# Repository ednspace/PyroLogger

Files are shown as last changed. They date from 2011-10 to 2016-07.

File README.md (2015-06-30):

For when you the Pyro, needs to log!!!
======================================

Summary
----

A long standing project (since early 2005) to log and provide real time graphing of wood, electric, or gas kiln firings.
This project by necessity requires a hardware and software combination and through the years many have been tried with 
varying degrees of success. Most attempts are preserved here for posterity sake.

The Current Version
-----------
The most recent version of the hardware uses the Teensy 3.1 for the microcontroller, a custom made daughter board that has an SD card and phone jack
 to connect the sensors. The sensors are [MAX31850K from Adafruit](http://www.adafruit.com/products/1727). The GUI is now handled with a customized interface
 for the amazing [MegunoLink](http://www.megunolink.com/).
 While buying modular hardware and using software that requires a modest licensing fee adds to the overall build cost it makes the 
 hardware and software a bit more accessible to the novice experimenter. 
 Hopefully this will enable more people to get at their kiln data and improve their future firings and learn from the ones they have done in the past.

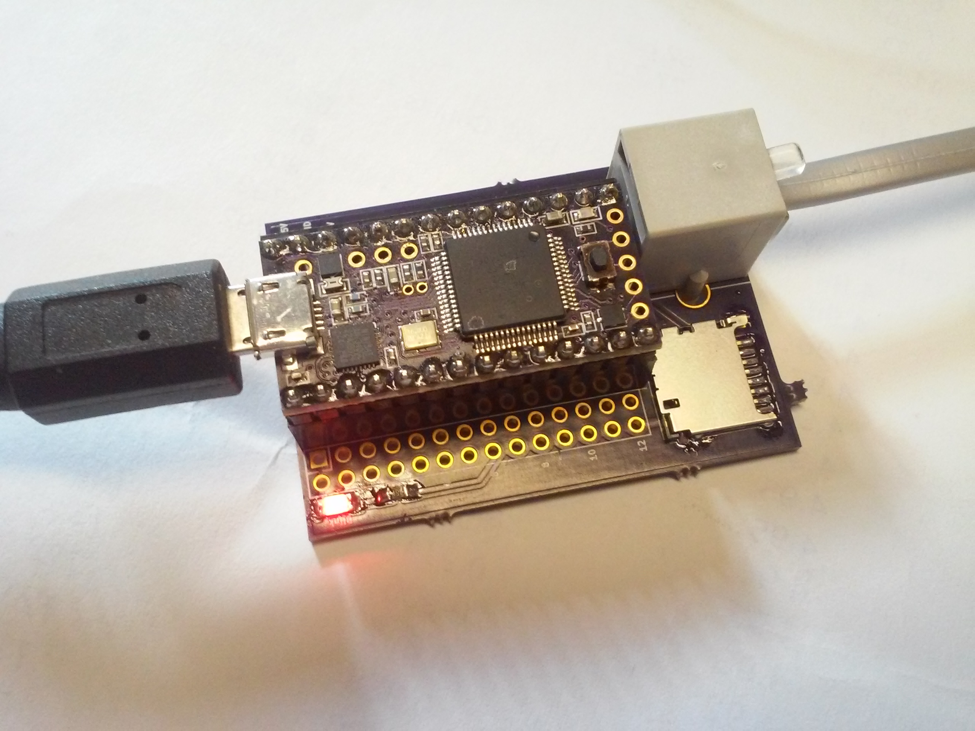
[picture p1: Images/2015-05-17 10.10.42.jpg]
Image of populated board

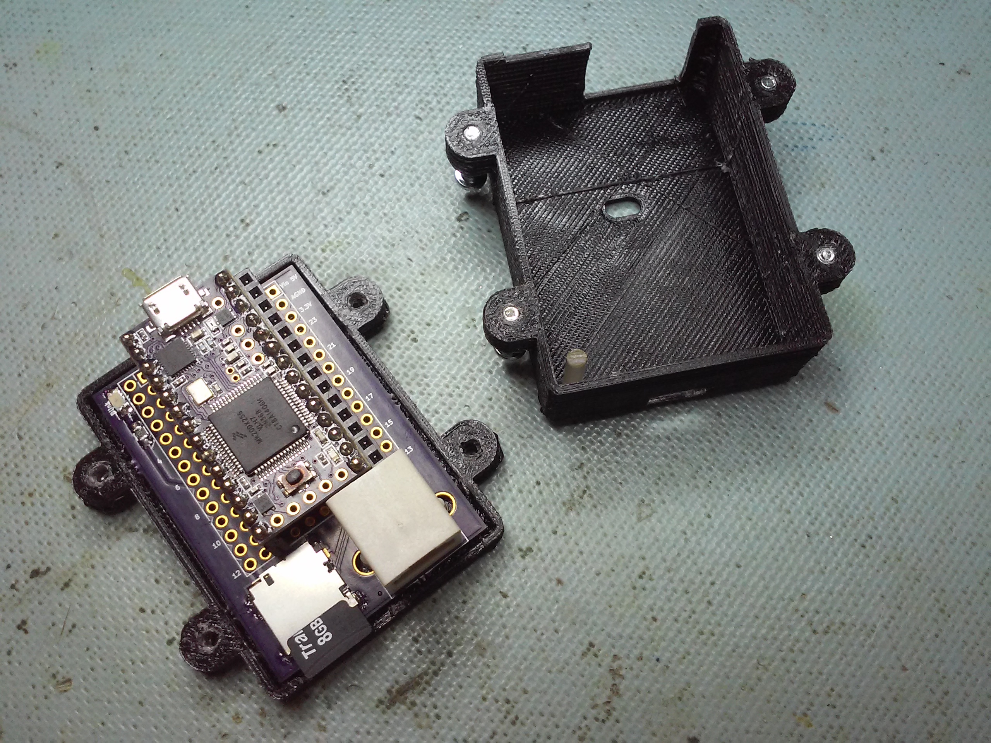
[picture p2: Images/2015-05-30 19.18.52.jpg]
Image of 3D enclosure split open

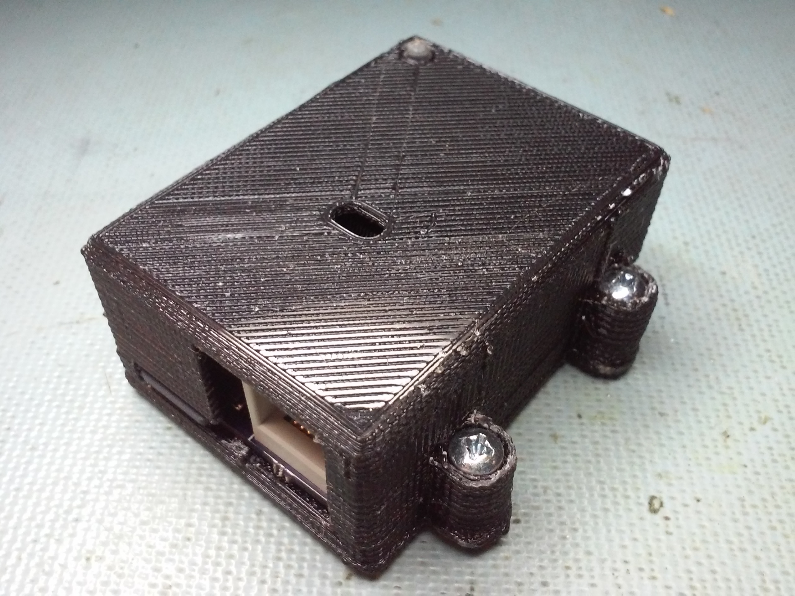
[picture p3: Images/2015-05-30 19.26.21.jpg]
Image of 3D enclosure closed up

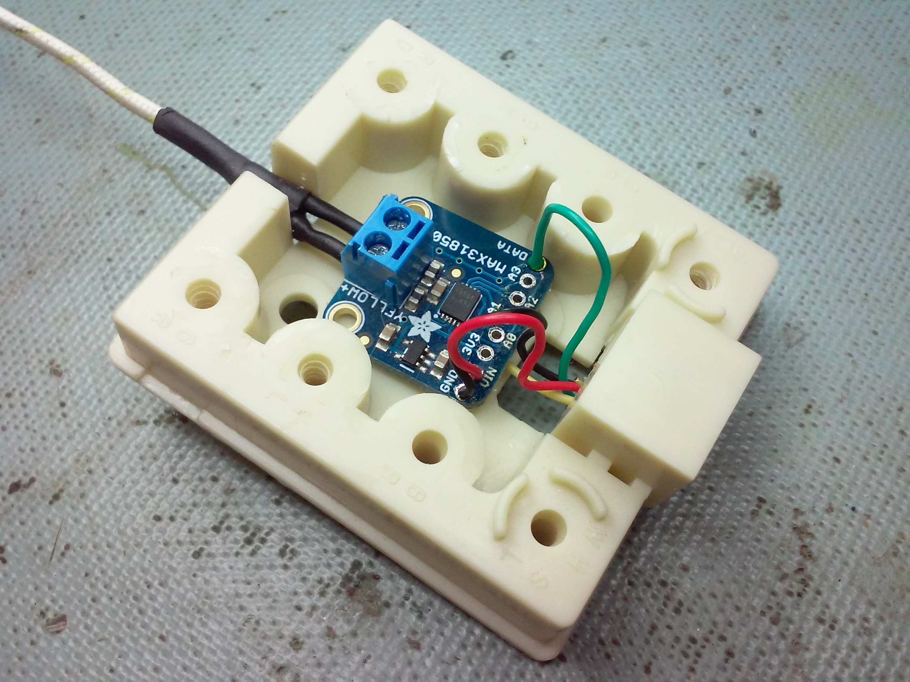
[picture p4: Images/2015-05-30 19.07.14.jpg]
Image of the sensor board in the phone box

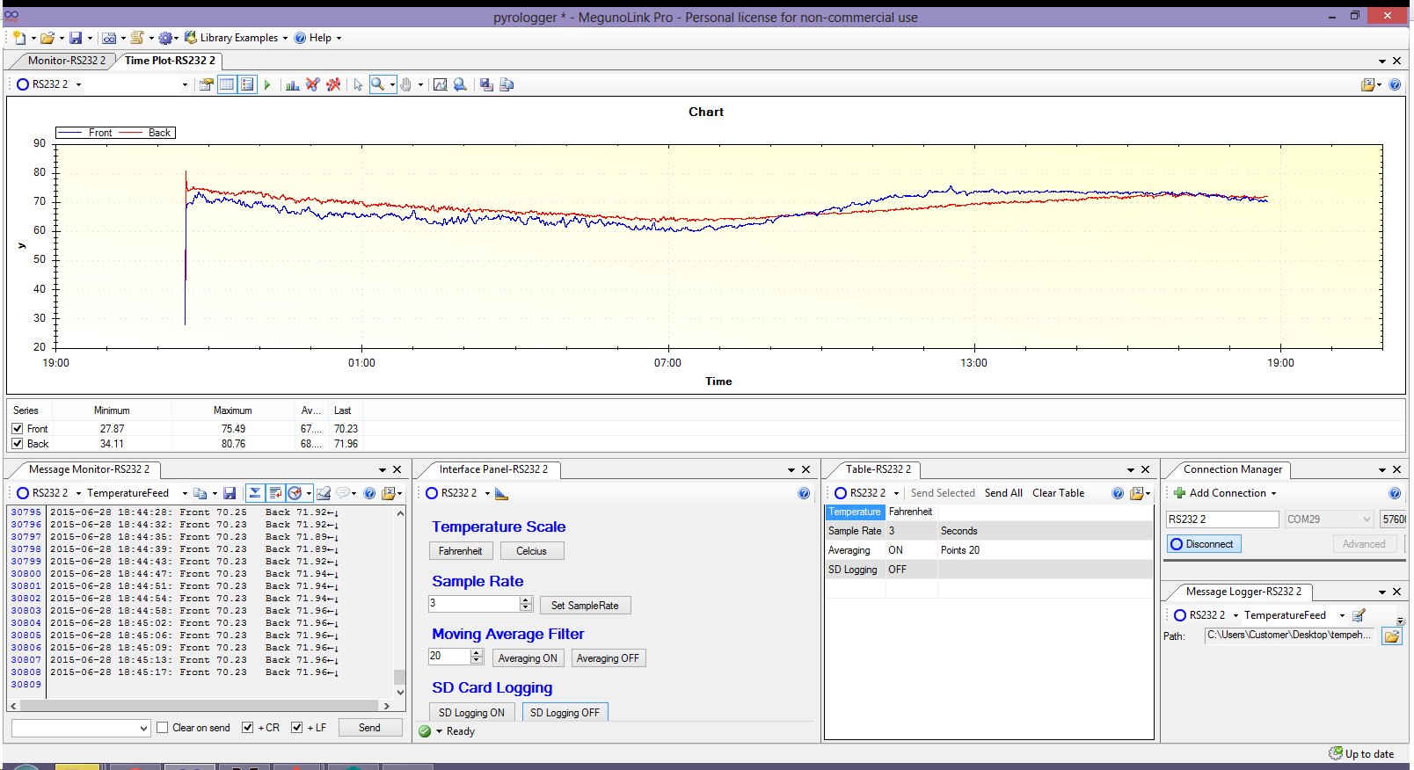
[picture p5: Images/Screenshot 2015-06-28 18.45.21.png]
Image of the GUI

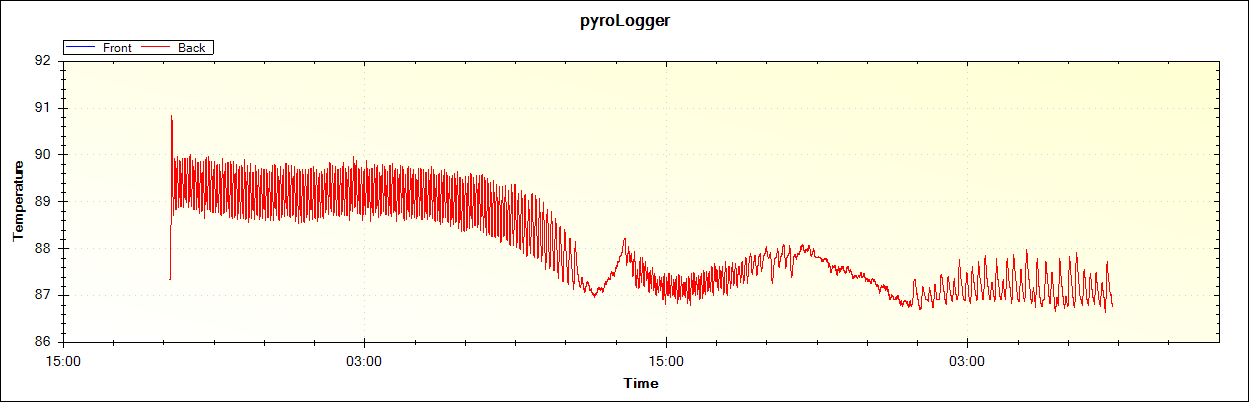
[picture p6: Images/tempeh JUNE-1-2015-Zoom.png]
Image of zoomed in Tempeh graph


History
-----
If you dig around in the archives you will find early versions of the code that relied on Python, WxPython for a GUI, and provided a front end for a custom piece of hardware. The hardware at that time was based on a microchip PIC microcontroller and addressed a one wire bus and a DS2760A to ultimately digitize two analog type K thermocouples. The combination of hardware and software was used to collect, display and log the temperature. Many variations of the code are here and all of hardware versions of the electronics also. Many early graphs generated with that hardware software combination are in the testing folder. Most of the work was done on the WxGauge and GUI versions. Its not very organized, but feel free to poke around and use what you need.

Enjoy... ED

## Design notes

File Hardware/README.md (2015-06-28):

Hardware Lives Here
---------

The folder Pyrologger_V3_KiCad contains the latest board files. Its a daughter board for 
the teensy 3.1 that has connections for the thermocouple sensors and an SD card.

The folder ds2760-pcb contains the orginal board files for the pyrometer 
sensor. The chip is a ds2760 lithium ion battery monitor from Maxim now 
Dallas Semiconductor.  It uses the one wire bus to get the mv drop over 
the shunt resistor which in this case is actually a type K 
thermocouple. The files where generated with Linux-PCB and the 
schematics are in gschem.  The LMD file is for driving an LPKF circuit 
board plotter to cut out the board.

The folder 16F88_FT232RL contains the board files and schematic for the 
microcontroller interface to the computer.  It uses a microchip 
technology 16F88 and an FTDI chip to make a serial connection through 
USB.  The microcontroller board is accessed with by the wxPython GUI 
software which collects the data and displays it on screen.  The board 
files where done with Eagle.

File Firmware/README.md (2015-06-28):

Latest Micro Code Lives Here
----
Current Version is in pyroLogger_V3_Teensy3.1
Enjoy... ED

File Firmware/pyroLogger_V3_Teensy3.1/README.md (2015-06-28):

Current Codebase
________________
This folder contains the newest code for the pyrologger project.
It uses Megunolink Pro as a GUI interface and computer display panel
to connect to the hardware and graph data coming from two thermocouple sensor 
modules.

The file pyrologger.mlx can be opened by Megunolink to display the GUI.

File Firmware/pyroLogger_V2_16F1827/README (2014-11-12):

PyrologgerV2

This is an updated version of the old Pyrologger codebase. It will feature a PyQT/QWT GUI interface to a custom hardware control board. The new board will have an upgraded microcontroller, the PIC 16F1827 and a Dallas 1 Wire Bus Master chip and an FTDI serial to USB converter for interaction with the computer.

It is planned to bring out all of the old Pyrologger features but finally move to a more robust hardware platform. There will eventually be software enhancements as well, once all the bugs are worked out with the new hardware. 

I will be keeping Firmware code, GUI code, and board files for the interface board as well as the thermocouple sensors all under this new GIT repository.

As they say, stay tuned!

LICENSE:

The Hardware and software in this project are released under the Creative Commons Attribution-Share Alike 3.0 United States License.

http://creativecommons.org/licenses/by-sa/3.0/deed.en_US

You may reproduce it for both your own personal use, and for commercial use if you provide a link to the original creator of the project on any documentation or website.

You may also modify the files, but you must then release them as well under the same terms.

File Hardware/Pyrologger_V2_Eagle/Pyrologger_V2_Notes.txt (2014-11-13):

Pyrologger

It seems I used the DS2760 for the sensor in the orginal design the new chip is now DS2762, its an upgrade from DS2760,DS2761 to the new DS2762. Its about 7.25 from mouser for a single chip...

DS2764 is a 2-wire version I2C otherwise looks the same, I think you can get a unique address...

Since I just saw a chip that claims to be latest greatest for thermocouples MAX3185 again I went to investigate. Most of these chips can go to extreme end for type K that a Kiln requires. From the data sheet.

VOUT = (41.276FV/NC) x (TR - TAMB)
where VOUT is the thermocouple output voltage (FV), TR
is the temperature of the remote thermocouple junction
(NC), and TAMB is the temperature of the device (NC).
Other thermocouple types use a similar straight-line
approximation but with different gain terms. Note that the
MAX31855 assumes a linear relationship between temperature
and voltage. Because all thermocouples exhibit
some level of nonlinearity, apply appropriate correction
to the device’s output data.

That last sentance scares me a little linear equation for a nonlinear device, I guess thats one way to do it...
Oh and at this time its $8.

Looks like if I use one wire and really want to use distances longer then a meter I may need to finally upgade to a bus maser chip, talk serial to it and let it handle the one wire bus. Course I have been living without this for a long long time now but...

DS2480 is the chip

And this is a good starter article http://www.maximintegrated.com/app-notes/index.mvp/id/4206

Looks like the DS2482 is the animal I need only a 1.66 little 8 pin bus master. Should be able to handle the bus and the micro can speak to it via I2C. Non Brainer

I have 2 sample chips of DS2762

and RJ11 socket with a footprint
https://www.sparkfun.com/products/132

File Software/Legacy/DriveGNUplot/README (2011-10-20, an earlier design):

Just a couple of perl scripts to plot data in gnuplot.
This was long before the wxPython GUI.
Here for archival purposes only...

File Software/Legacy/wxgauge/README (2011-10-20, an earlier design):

This is where the current version of the code lives...
wxthermo.py Reads and logs to the screen one thermocouple
wxthermo2.py Reads and logs two thermocouples
thermofunctions.py is an include file for repetitive tasks
images holds some of the icons for the GUI
graphs is a test folder containing saved graphs

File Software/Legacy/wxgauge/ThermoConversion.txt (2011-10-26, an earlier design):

Question:
How do you convert K-type thermocouple voltage to temperature using NIST polynomials?

Answer:
The NIST polynomials will produce a temperature conversion accuracy typically less than 0.06 degrees C error for K-type thermocouple.

NIST (National Institute of Standards and Technology) has published tables and equations that describe the voltage/temperature relationship. See PB93-190338, Temperature-Electromotive Force Reference Functions and Tables for the Letter-Designated Thermocouple Types Based on the ITS-90. NIST provides two forms of polynomials. The first provides voltage as a function of temperature, and the second provides temperature as a function of voltage. Both of these forms will be used in the procedure described here for doing a thermocouple temperature conversion.

The NIST tables and equations are all based on one end of the thermocouple (reference junction end) being at a temperature of 0 degrees Celsius. It is possible to avoid having a 0 degree reference junction. If the temperature of the reference junction is accurately known, then by using both the forward and inverse NIST polynomials the temperature of the thermocouple can be computed.

On a thermocouple, voltage is produced across the thermocouple leads that is proportional to the difference in temperature from one end of the thermocouple wire to the other. It is important to understand that voltage does not develop at the thermocouple junction but instead the voltage develops in the wire were ever a temperature gradient exists in the wire pair. Thermocouple:

      ------------------------------------------------------------\
     |    |--------->--------|    |------------->--------------|   \
     V  Vref                 |  Vmeas                          |    O    
     |    |----------<-------|    |-------------<--------------|   /
     -------------------------------------------------------------/
    ^                          ^                                    ^
    |                          |                                    |
  0 deg C                    Tref                                   T

The above diagram shows that: V If we know Tref, then Vref is calculated using the temperature to voltage form of the NIST equations. Vmeas is the voltage measured on the thermocouple. Adding Vmeas to the calculated Vref yields the voltage V that is then applied to the NIST voltage-to-temperature thermocouple equation to produce the final thermocouple temperature.

Tref is usually at about room temperature. A thermistor is usually used to sense this temperature.

Here is the complete algorithm which assumes that a 5K ohm thermistor is used to sense the reference junction temperature.

1. Measure the resistance of the thermistor on the reference junction. Compute the temperature of the reference junction (Tref) from the resistance reading. The following equation has less than 0.022 Deg C error for resistance between 92.7 (150 deg C) and 3.685e6 (-80 Deg C).

 Tref = temp. in degrees C
 
 Thr_ohms = resistance of 5K thermistor
 
 A = 1.28463e-3
 
 B = 0.23625e-3
 
 C = 9.2697e-8 
 
 W = ln(Thr_ohms)
 
 Tref = 1 / (A + W * (B+C * W*W)) - 273.15

The function ln is the logarithm (base e) or natural logarithm. Note that in HP BASIC, this is the keyword LOG.

2. Measure the voltage on the thermocouple connected to a channel (Vmeas).

3. Convert the thermistor temperature (Tref) to the equivalent thermocouple voltage (Vref). Use the temperature to voltage characteristics of the thermocouple measured in step 2.

K-type thermocouple temperature to voltage conversion:

 Vref = c0 + c1*Tref + c2*Tref^2 + c3*Tref^3 + c4*Tref^4 + c5*Tref^5 + 

 c6*Tref^6 + c7*Tref^7 + c8*Tref^8 + c9*Tref^9

The coefficients for temperature range 0 to 1372 deg C are:

 c0 = -1.7600413686 * 10^-2

 c1 = 3.8921204975 * 10^-2

 c2 = 1.8558770032 * 10^-5

 c3 = -9.9457592874 * 10^-8

 c4 = 3.1840945719 * 10^-10

 c5 = -5.6072844889 * 10^-13

 c6 = 5.6075059059 * 10^-16

 c7 = -3.2020720003 * 10^-19

 c8 = 9.7151147152 * 10^-23

 c9 = -1.2104721275 * 10^-26

4. Compute the compensated voltage (V) with the following formula: V=Vmeas + Vref

5. Convert the compensated voltage (V) calculated in step 4 to temperature (T). The equation for converting voltage (millivolts) to K-type thermocouple temperature in degrees Celsius is:

 T = c0 + c1*V + c2*V^2 + c3*V^3 + c4*V^4 + c5*V^5 + c6*V^6 + c7*V^7 +

 c8*V^8 + c9*V^9

 The coefficients for Temperature range -200 deg C to 0 deg C 

 Voltage range -5.891 mV to 0 mV

 Error Range .04 deg C to -.02 deg C are:

 C0 = 0

 C1 = 2.5173462 * 10^1

 C2 = -1.1662878

 C3 = -1.0833638

 C4 = -8.9773540 * 10^-1

 C5 = -3.7342377 * 10^-1

 C6 = -8.6632643 * 10^-2

 C7 = -1.0450598 * 10^-2

 C8 = -5.1920577 * 10^-4

 C9 = 0

 The coefficients for Temperature range 0 deg C to 500 deg C

 Voltage range 0 mV to 20.644 mV

 Error range .04 deg C to -.05 deg C are:

 C0 = 0

 C1 = 2.508355 * 10^1

 C2 = 7.860106 * 10^-2

 C3 = -2.503131 * 10^-1

 C4 = 8.315270 * 10^-2

 C5 = -1.228034 * 10^-2

 C6 = 9.804036 * 10^-4

 C7 = -4.413030 * 10^-5

 C8 = 1.057734 * 10^-6

 C9 = -1.052755 * 10^-8 

 The coefficients for Temperature range 500 deg C to 1372 deg C

 Voltage range 20.644 mV to 54.886 mV

 Error range .06 deg C to -.05 deg C are:

 C0 = -1.318058 * 10^2

 C1 = 4.830222 * 10^1

 C2 = -1.646031 

 C3 = 5.464731 * 10^-2

 C4 = -9.650715 * 10^-4

 C5 = 8.802193 * 10^-6

 C6 = -3.110810 * 10^-8

 C7 = 0

 C8 = 0

 C9 = 0

Remember to carry the correct units when using the tables or when using the polynomials in steps 3 and 5. For example, voltage in milivolts, temperature in degrees C.

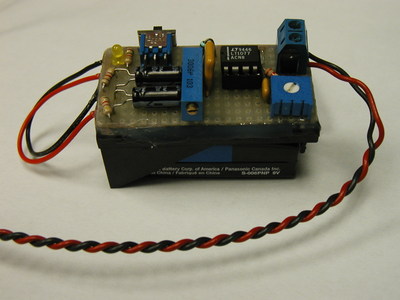
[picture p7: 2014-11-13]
Hardware/FakeThermocouple/fake_thermo1.jpg

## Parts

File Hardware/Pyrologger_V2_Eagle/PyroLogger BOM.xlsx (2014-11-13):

Part Description | Mouser URL | Digikey URL | Package Type | Number | Price Each | Subtotal | Notes
Metal Case | http://www.mouser.com/ProductDetail/Hammond-Manufacturing/1455C801/ |  |  | 1 | $11.00 | $11.00 | Size 3.15 x 2.125 x 0.91 (Price break at 5 to 11.00) 13.08 individually
ft232rl FTDI serial to USB chip | http://www.mouser.com/Search/Refine.aspx?Keyword=ft232rl |  | SSOP-28 | 1 | $4.50 | $4.50
16F1827 | http://www.mouser.com/Search/ProductDetail.aspx |  | SOIC-18 Wide | 1 | $1.79 | $1.79
DS2482 | http://www.mouser.com/ProductDetail/Maxim-Integrated-Products/DS2482S-100+/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 |  | SOIC8 | 1 | $1.59 |  | This is the I2C BusMaster Chip
Boards made at itead | http://iteadstudio.com/store/index.php?main_page=product_info&cPath=19_20&products_id=508 |  |  | 1 | $3.12 | $3.12 | 8 boards for 25.00 Extra 2cm x 5cm for sensor
USB Connector | http://www.mouser.com/ProductDetail/Hirose-Connector/UX60SC-MB-5ST01/ |  | SMD Mini-B | 1 | $0.56 | $0.56 | Requires a footprint change | Can get these here for only .14 each WOW http://www.mdfly.com/index.php?main_page=product_info&cPath=65_67_133&products_id=155
Indicator LED3MM | http://www.mouser.com/ProductDetail/Kingbright/WP3A8GD/ |  | T1 | 3 | $0.05 | $0.15 | Need 3 different colors TX RX Power (Red, Yellow, Green) Onlly need to buy 10 to get this price break
LEDCHIPLED_1206 LED2 | http://www.mouser.com/ProductDetail/OSRAM-Opto-Semiconductors/LG-N971-KN-1/ |  | 1206 | 1 | $0.08 | $0.08
.1uF Cap | http://www.mouser.com/Search/ProductDetail.aspx |  | 1206 | 3 | $0.01 | $0.04
330 Resistor | http://www.mouser.com/ProductDetail/Xicon/301-330-RC/ |  | 1206 | 3 | $0.02 | $0.06
P-Channel FET | http://www.mouser.com/Search/ProductDetail.aspx?R=BSS84virtualkey51210000virtualkey512-BSS84 |  | sot-23 | 1 | 0.08 | $0.08 | Needed for High Pullup
Board and Sensor Set from Laen |  |  |  | 1 | $20.66 | $61.98 | This price would be about half this if we ordered from Itead

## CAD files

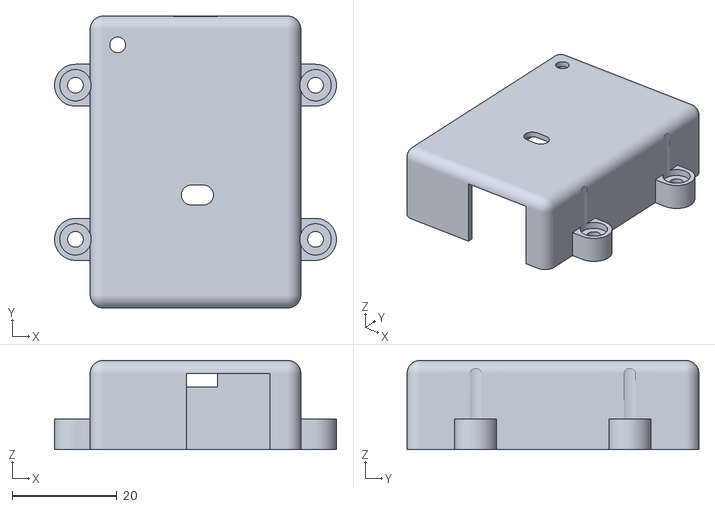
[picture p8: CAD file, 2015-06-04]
3DPrints/Enclosure/Pyrologger_V3_Enclosure_Top.stl
53.8 x 55.7 x 17.0

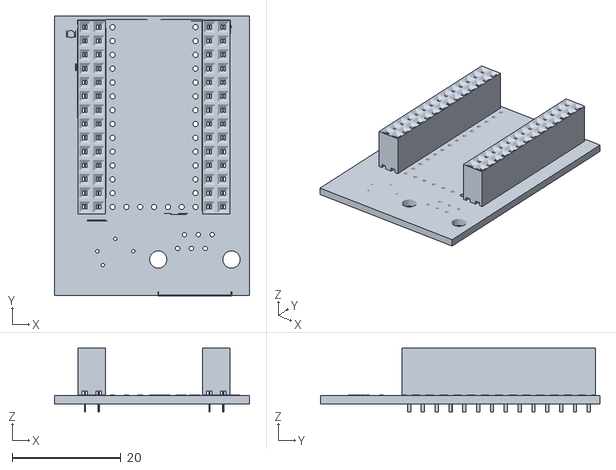
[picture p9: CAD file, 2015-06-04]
Hardware/Pyrologger_V3_KiCad/Pyrologger_V3.stl
35.8 x 51.4 x 11.7

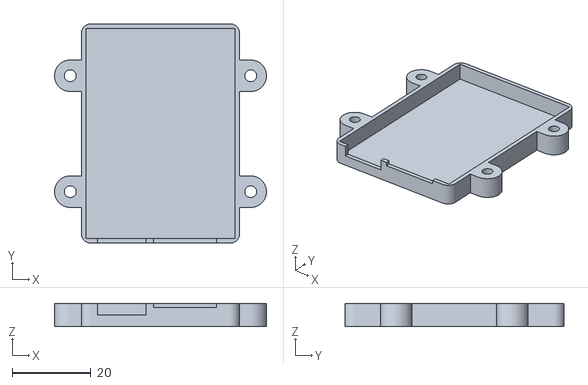
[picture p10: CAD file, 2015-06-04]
3DPrints/Enclosure/Pyrologger_V3_Enclosure_Bottom.stl
53.8 x 55.7 x 5.88

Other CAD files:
3DPrints/Enclosure/Pyrologger_V3_Board.stl

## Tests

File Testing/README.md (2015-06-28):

Testing
---------
Mostly old graphs logged with the various hardware software combinations.

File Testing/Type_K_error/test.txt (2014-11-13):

1 0.039
2 0.079
3 0.119
4 0.158
5 0.198
6 0.238
7 0.277
8 0.317
9 0.357
10 0.397
11 0.437
12 0.477
13 0.517
14 0.557
15 0.597
16 0.637
17 0.677
18 0.718
19 0.758
20 0.798
21 0.838
22 0.879
23 0.919
24 0.960
25 1.000
26 1.041
27 1.081
28 1.122
29 1.163
30 1.203
31 1.244
32 1.285
33 1.326
34 1.366
35 1.407
36 1.448
37 1.489
38 1.530
39 1.571
40 1.612
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

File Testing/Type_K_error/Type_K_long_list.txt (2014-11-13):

   0  0.000  0.039  0.079  0.119  0.158  0.198  0.238  0.277  0.317  0.357  0.397 
  10  0.397  0.437  0.477  0.517  0.557  0.597  0.637  0.677  0.718  0.758  0.798 
  20  0.798  0.838  0.879  0.919  0.960  1.000  1.041  1.081  1.122  1.163  1.203 
  30  1.203  1.244  1.285  1.326  1.366  1.407  1.448  1.489  1.530  1.571  1.612 
  40  1.612  1.653  1.694  1.735  1.776  1.817  1.858  1.899  1.941  1.982  2.023 
  50  2.023  2.064  2.106  2.147  2.188  2.230  2.271  2.312  2.354  2.395  2.436 
  60  2.436  2.478  2.519  2.561  2.602  2.644  2.685  2.727  2.768  2.810  2.851 
  70  2.851  2.893  2.934  2.976  3.017  3.059  3.100  3.142  3.184  3.225  3.267 
  80  3.267  3.308  3.350  3.391  3.433  3.474  3.516  3.557  3.599  3.640  3.682 
  90  3.682  3.723  3.765  3.806  3.848  3.889  3.931  3.972  4.013  4.055  4.096 
 100  4.096  4.138  4.179  4.220  4.262  4.303  4.344  4.385  4.427  4.468  4.509 
 110  4.509  4.550  4.591  4.633  4.674  4.715  4.756  4.797  4.838  4.879  4.920 
 120  4.920  4.961  5.002  5.043  5.084  5.124  5.165  5.206  5.247  5.288  5.328 
 130  5.328  5.369  5.410  5.450  5.491  5.532  5.572  5.613  5.653  5.694  5.735 
 140  5.735  5.775  5.815  5.856  5.896  5.937  5.977  6.017  6.058  6.098  6.138 
 150  6.138  6.179  6.219  6.259  6.299  6.339  6.380  6.420  6.460  6.500  6.540 
 160  6.540  6.580  6.620  6.660  6.701  6.741  6.781  6.821  6.861  6.901  6.941 
 170  6.941  6.981  7.021  7.060  7.100  7.140  7.180  7.220  7.260  7.300  7.340 
 180  7.340  7.380  7.420  7.460  7.500  7.540  7.579  7.619  7.659  7.699  7.739 
 190  7.739  7.779  7.819  7.859  7.899  7.939  7.979  8.019  8.059  8.099  8.138 
 200  8.138  8.178  8.218  8.258  8.298  8.338  8.378  8.418  8.458  8.499  8.539 
 210  8.539  8.579  8.619  8.659  8.699  8.739  8.779  8.819  8.860  8.900  8.940 
 220  8.940  8.980  9.020  9.061  9.101  9.141  9.181  9.222  9.262  9.302  9.343 
 230  9.343  9.383  9.423  9.464  9.504  9.545  9.585  9.626  9.666  9.707  9.747 
 240  9.747  9.788  9.828  9.869  9.909  9.950  9.991 10.031 10.072 10.113 10.153 
 250 10.153 10.194 10.235 10.276 10.316 10.357 10.398 10.439 10.480 10.520 10.561 
 260 10.561 10.602 10.643 10.684 10.725 10.766 10.807 10.848 10.889 10.930 10.971 
 270 10.971 11.012 11.053 11.094 11.135 11.176 11.217 11.259 11.300 11.341 11.382 
 280 11.382 11.423 11.465 11.506 11.547 11.588 11.630 11.671 11.712 11.753 11.795 
 290 11.795 11.836 11.877 11.919 11.960 12.001 12.043 12.084 12.126 12.167 12.209 
 300 12.209 12.250 12.291 12.333 12.374 12.416 12.457 12.499 12.540 12.582 12.624 
 310 12.624 12.665 12.707 12.748 12.790 12.831 12.873 12.915 12.956 12.998 13.040 
 320 13.040 13.081 13.123 13.165 13.206 13.248 13.290 13.331 13.373 13.415 13.457 
 330 13.457 13.498 13.540 13.582 13.624 13.665 13.707 13.749 13.791 13.833 13.874 
 340 13.874 13.916 13.958 14.000 14.042 14.084 14.126 14.167 14.209 14.251 14.293 
 350 14.293 14.335 14.377 14.419 14.461 14.503 14.545 14.587 14.629 14.671 14.713 
 360 14.713 14.755 14.797 14.839 14.881 14.923 14.965 15.007 15.049 15.091 15.133 
 370 15.133 15.175 15.217 15.259 15.301 15.343 15.385 15.427 15.469 15.511 15.554 
 380 15.554 15.596 15.638 15.680 15.722 15.764 15.806 15.849 15.891 15.933 15.975 
 390 15.975 16.017 16.059 16.102 16.144 16.186 16.228 16.270 16.313 16.355 16.397 
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

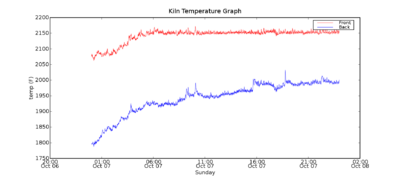
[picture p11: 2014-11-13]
Testing/Anagama_2007_oct/Thumbs/oct07.png

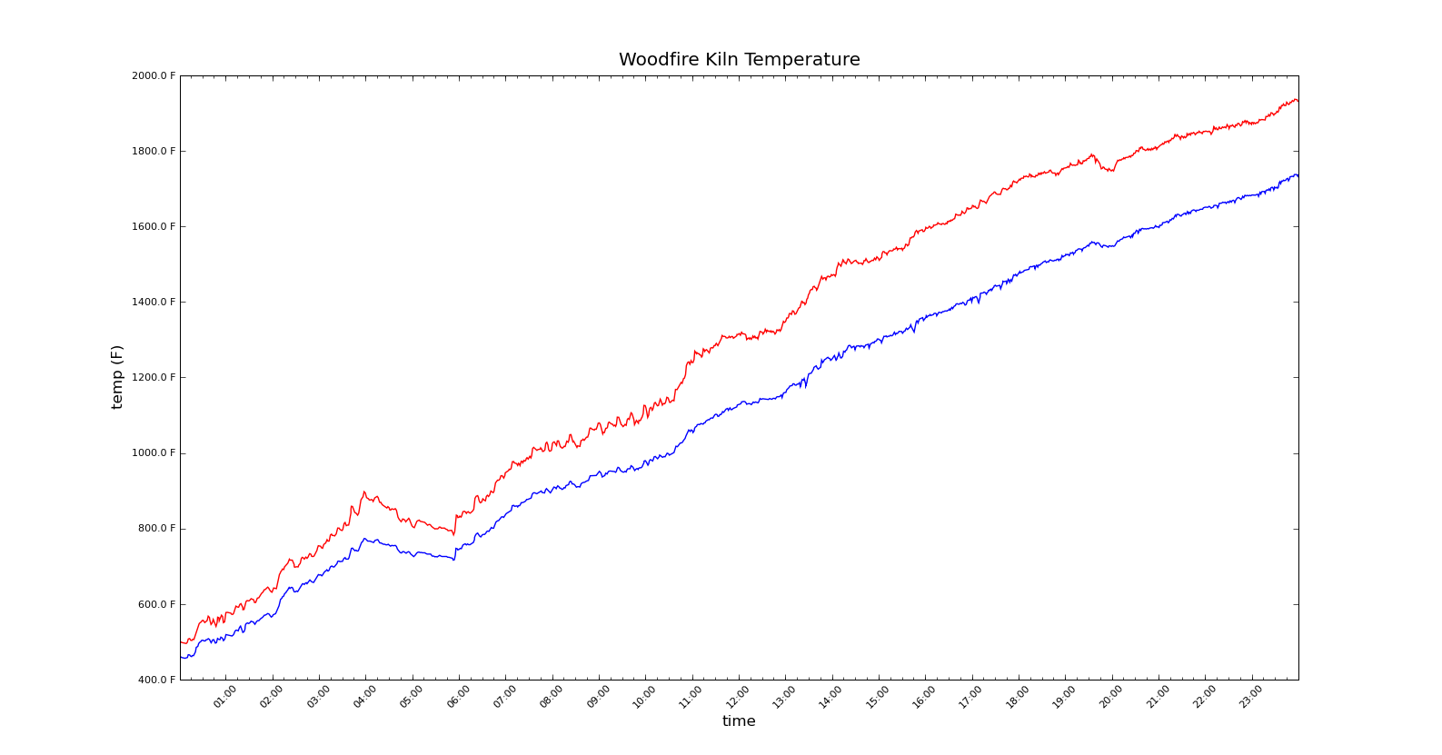
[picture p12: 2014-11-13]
Testing/Anagama_2010_april/day2.png

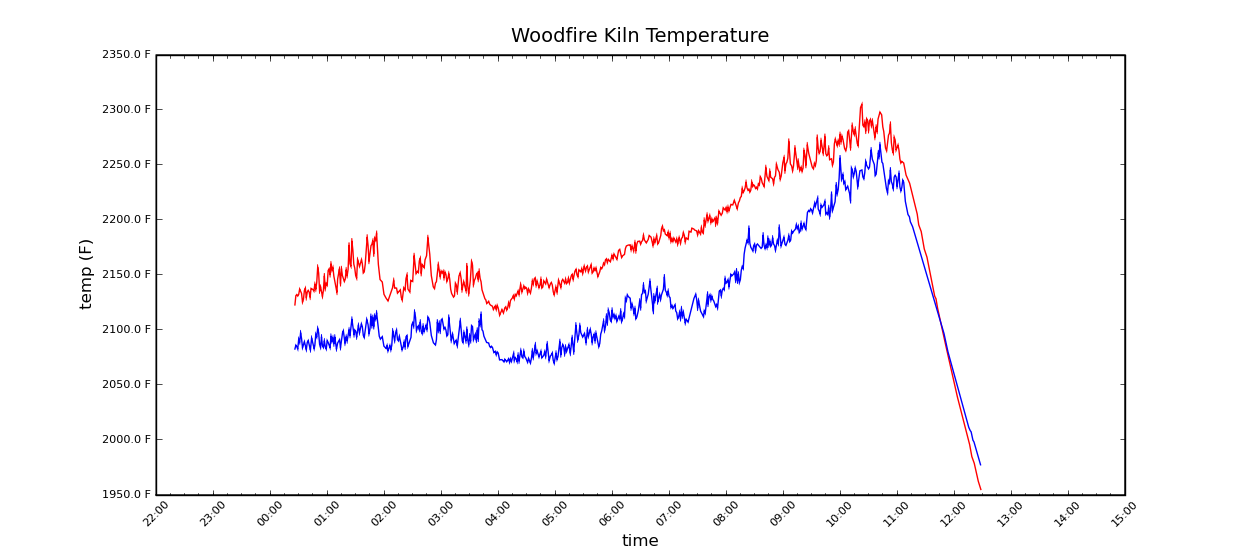
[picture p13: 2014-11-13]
Testing/Anagama_2009_april/day5.png

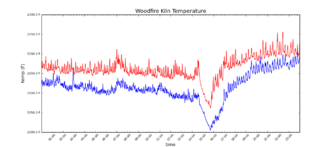
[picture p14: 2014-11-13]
Testing/Anagama_2010_oct/thumbs/day4.png

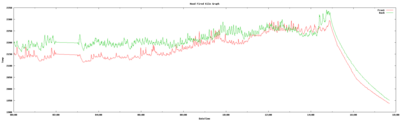
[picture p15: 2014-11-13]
Testing/Anagama_2007_march/Thumbs/march11.png

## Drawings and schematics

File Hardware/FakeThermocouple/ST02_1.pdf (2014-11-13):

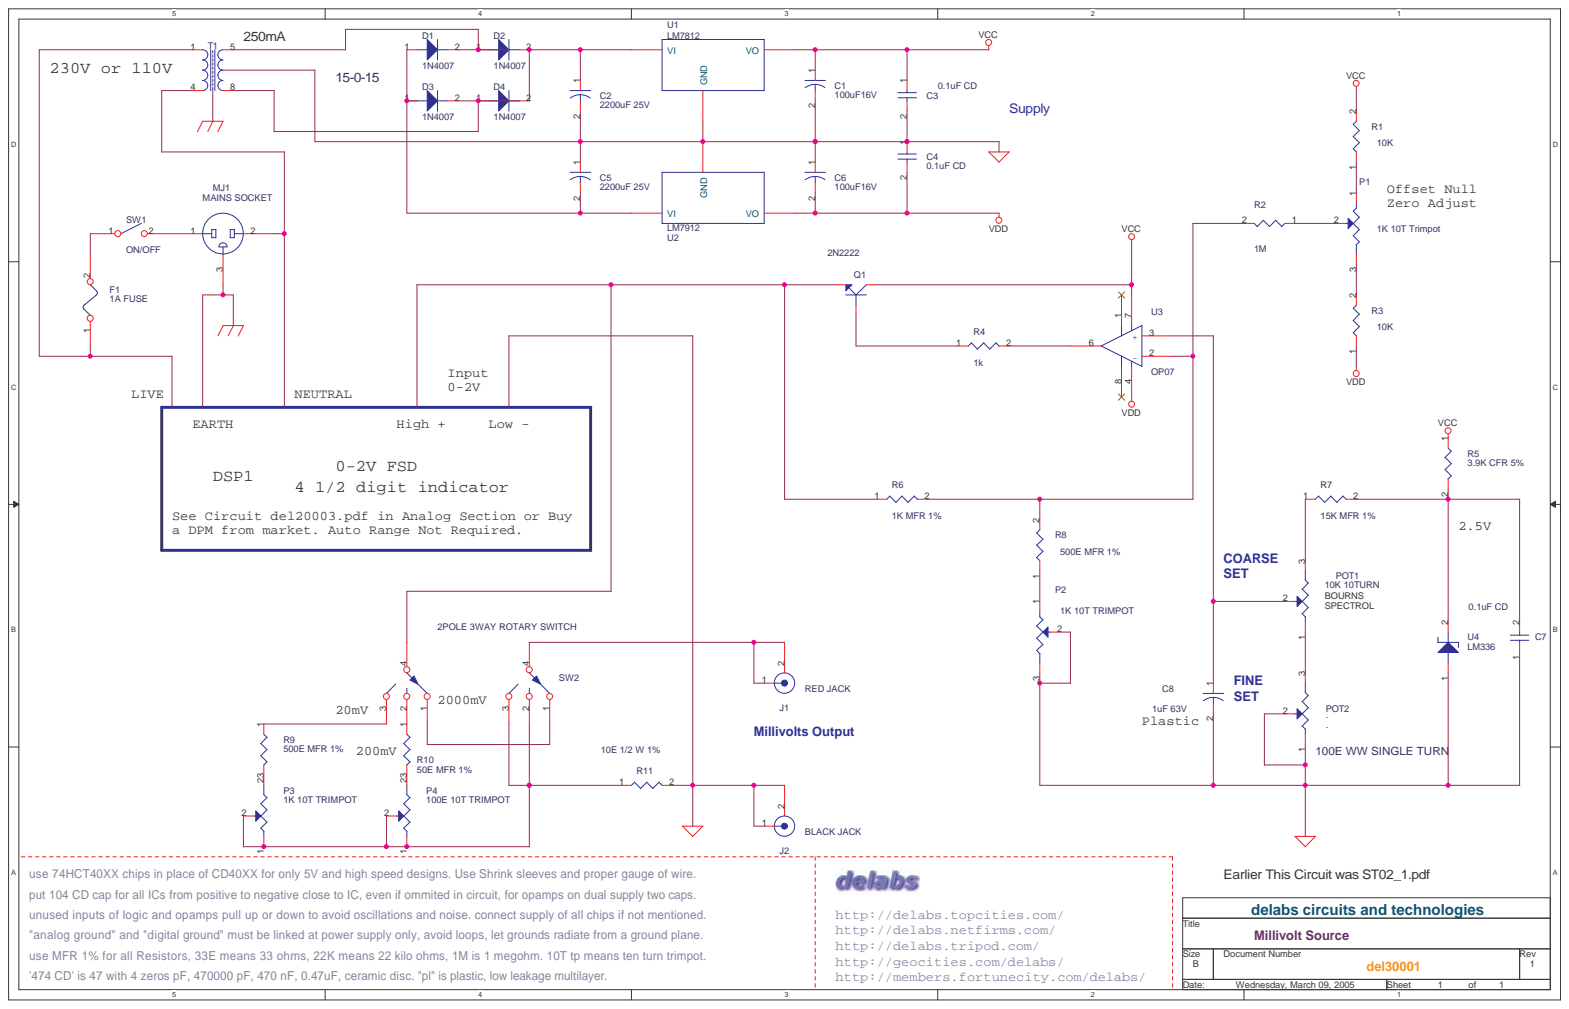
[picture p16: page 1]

See Circuit del20003.pdf in Analog Section or Buy
a DPM from market. Auto Range Not Required.

use 74HCT40XX chips in place of CD40XX for only 5V and high speed designs. Use Shrink sleeves and proper gauge of wire.
put 104 CD cap for all ICs from positive to negative close to IC, even if ommited in circuit, for opamps on dual supply two caps.
unused inputs of logic and opamps pull up or down to avoid oscillations and noise. connect supply of all chips if not mentioned.
"analog ground" and "digital ground" must be linked at power supply only, avoid loops, let grounds radiate from a ground plane.
use MFR 1% for all Resistors, 33E means 33 ohms, 22K means 22 kilo ohms, 1M is 1 megohm. 10T tp means ten turn trimpot.
'474 CD' is 47 with 4 zeros pF, 470000 pF, 470 nF, 0.47uF, ceramic disc. "pl" is plastic, low leakage multilayer.

Earlier This Circuit was ST02
delabs circuits and technologies
Millivolt Source

http://delabs.topcities.com/
http://delabs.netfirms.com/
http://delabs.tripod.com/
http://geocities.com/delabs/
http://members.fortunecity.com/delabs/

Size B | Document Number del30001 | Rev 1

Date: Wednesday, March 09, 2005 | Sheet 1 of 1

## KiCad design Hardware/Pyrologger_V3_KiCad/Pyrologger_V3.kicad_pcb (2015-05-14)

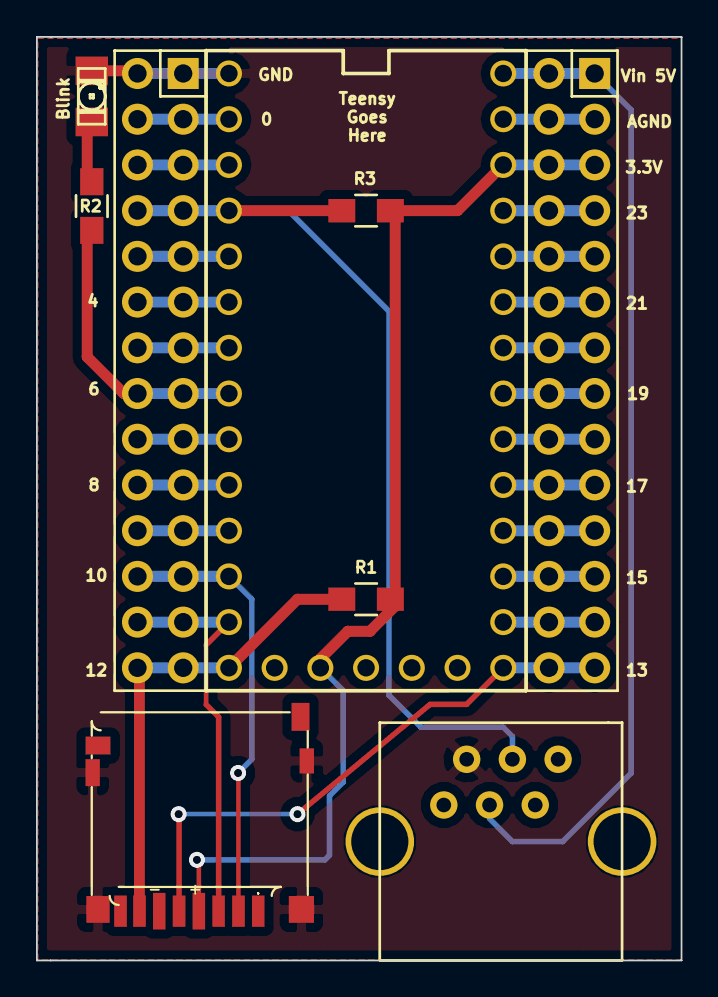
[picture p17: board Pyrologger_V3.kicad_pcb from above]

Board: 2 copper layers, 35.8 x 51.3 mm, 9 parts (0 on the bottom side), 29 nets.

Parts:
D1: LED; LED-1206
J1: RJ12; RJ12_E
P1, P2: CONN_02X14; Socket_Strip_Straight_2x14
R1: 10K; R_0805_HandSoldering
R2: 330; R_0805_HandSoldering
R3: 4.7K; R_0805_HandSoldering
U1: MICRO-SDCARD_MICRO-SDCARD; DM3D-MicroSD
U2: TEENSY_3.1_BASIC_TEENSY_3.1_BASIC; TEENSY_3.1_BASIC

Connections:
+3.3V: P2.5, P2.6, R1.1, R3.1, U2.3.3V
+5V: J1.3, P2.1, P2.2, U2.VIN
/AGND: P2.3, P2.4, U2.AGND
/DQ: J1.4, P1.7, P1.8, R3.2, U2.2
/MISO: P1.27, P1.28, R1.2, U1.DAT0, U2.12
/MOSI: P1.25, P1.26, U1.CMD, U2.11
/PIN0: P1.3, P1.4, U2.0
/PIN1: P1.5, P1.6, U2.1
/PIN3: P1.9, P1.10, U2.3
/PIN4: P1.11, P1.12, U2.4
/PIN5: P1.13, P1.14, U2.5
/PIN6: P1.15, P1.16, R2.1, U2.6
/PIN7: P1.17, P1.18, U2.7
/PIN8: P1.19, P1.20, U2.8
/PIN9: P1.21, P1.22, U2.9
/PIN14: P2.25, P2.26, U2.14/A
/PIN15: P2.23, P2.24, U2.15/A
/PIN16: P2.21, P2.22, U2.16/A
/PIN17: P2.19, P2.20, U2.17/A
/PIN18: P2.17, P2.18, U2.18/A
/PIN19: P2.15, P2.16, U2.19/A
/PIN20: P2.13, P2.14, U2.20/A
/PIN21: P2.11, P2.12, U2.21/A
/PIN22: P2.9, P2.10, U2.22/A
/PIN23: P2.7, P2.8, U2.23/A
/SCK: P2.27, P2.28, U1.CLK, U2.13
/SS: P1.23, P1.24, U1.CD/D, U2.10
GND: D1.2, J1.2, P1.1, P1.2, U1.GND1, U1.GND2, U1.GND3, U1.GND4, U2.GND
unnamed: D1.1, R2.2

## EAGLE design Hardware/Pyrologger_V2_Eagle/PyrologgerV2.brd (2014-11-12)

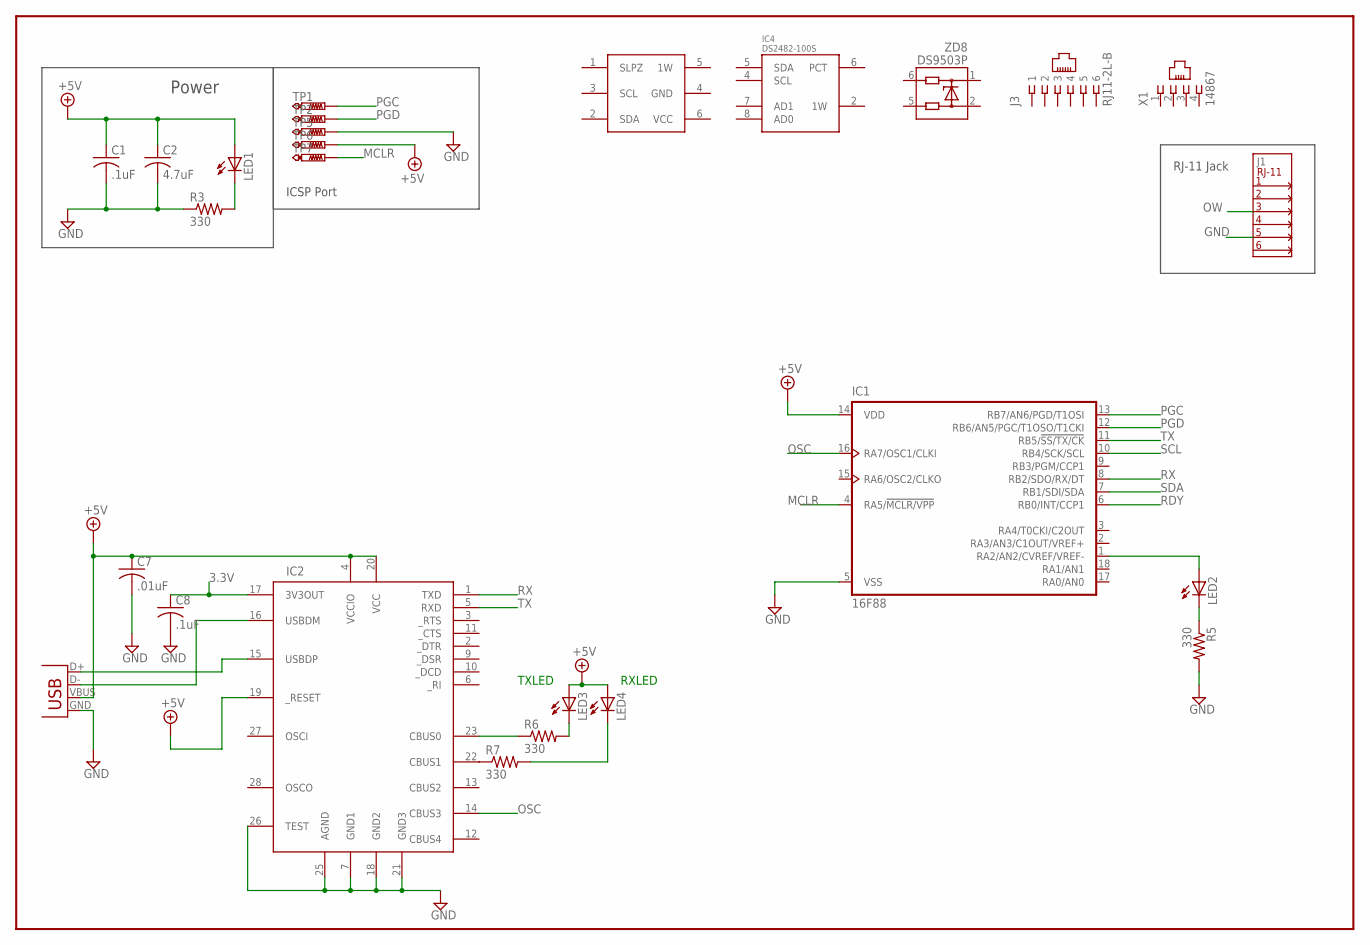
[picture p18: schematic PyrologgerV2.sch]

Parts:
C1, C8: .1uF; C1206@1
C2: 4.7uF; C1206@1
C7: .01uF; C1206@1
IC1: 16F88; SO-18W
IC2: FT232RL; SSOP28DB
IC4: DS2482-100S; SO08
J1: CONN-RJ11
J3: RJ11-2L-B; RJ11-NO_SHIELD
LED1, LED3, LED4: LED3MM
LED2: LEDCHIPLED_1206; CHIPLED_1206
R3, R5, R6, R7: 330; R1206
TP1, TP2, TP5, TP6, TP7: PTR1PAD1-13; P1-13@1
U1: DS2483; TSOT23
X1: 14867
X4: USBMINIB; USB-MINIB
ZD8: DS9503P; TSOC6

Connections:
3.3V: C8.1, IC2.17 (3V3OUT)
+5V: C1.1, C2.1, C7.1, IC1.14 (VDD), IC2.4 (VCCIO), IC2.19 (_RESET), IC2.20 (VCC), LED1.A, LED3.A, LED4.A, TP6.TP, X4.VBUS
GND: C1.2, C2.2, C7.2, C8.2, IC1.5 (VSS), IC2.7 (GND1), IC2.18 (GND2), IC2.21 (GND3), IC2.25 (AGND), IC2.26 (TEST), IC4.3 (GND), J1.5, R3.1, R5.2, TP5.TP, U1.4 (GND), X4.GND
MCLR: IC1.4 (RA5/!MCLR/VPP), TP7.TP
unnamed: IC2.15 (USBDP), X4.D+
unnamed: IC2.16 (USBDM), X4.D-
unnamed: LED3.K (C), R6.2
unnamed: LED4.K (C), R7.2
unnamed: IC2.23 (CBUS0), R6.1
unnamed: IC2.22 (CBUS1), R7.1
unnamed: LED1.K (C), R3.2
unnamed: IC1.1 (RA2/AN2/CVREF/VREF-), LED2.A
unnamed: LED2.C, R5.1
OSC: IC1.16 (RA7/OSC1/CLKI), IC2.14 (CBUS3)
OW: J1.3
PGC: IC1.13 (RB7/AN6/PGD/T1OSI), TP1.TP
PGD: IC1.12 (RB6/AN5/PGC/T1OSO/T1CKI), TP2.TP
RDY: IC1.6 (RB0/INT/CCP1)
RX: IC1.8 (RB2/SDO/RX/DT), IC2.1 (TXD)
SCL: IC1.10 (RB4/SCK/SCL)
SDA: IC1.7 (RB1/SDI/SDA)
TX: IC1.11 (RB5/!SS/TX/CK), IC2.5 (RXD)
VCC: U1.6 (VCC)
VDD: IC4.1 (VDD)

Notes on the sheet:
TXLED
RXLED
Power
ICSP Port
RJ-11 Jack

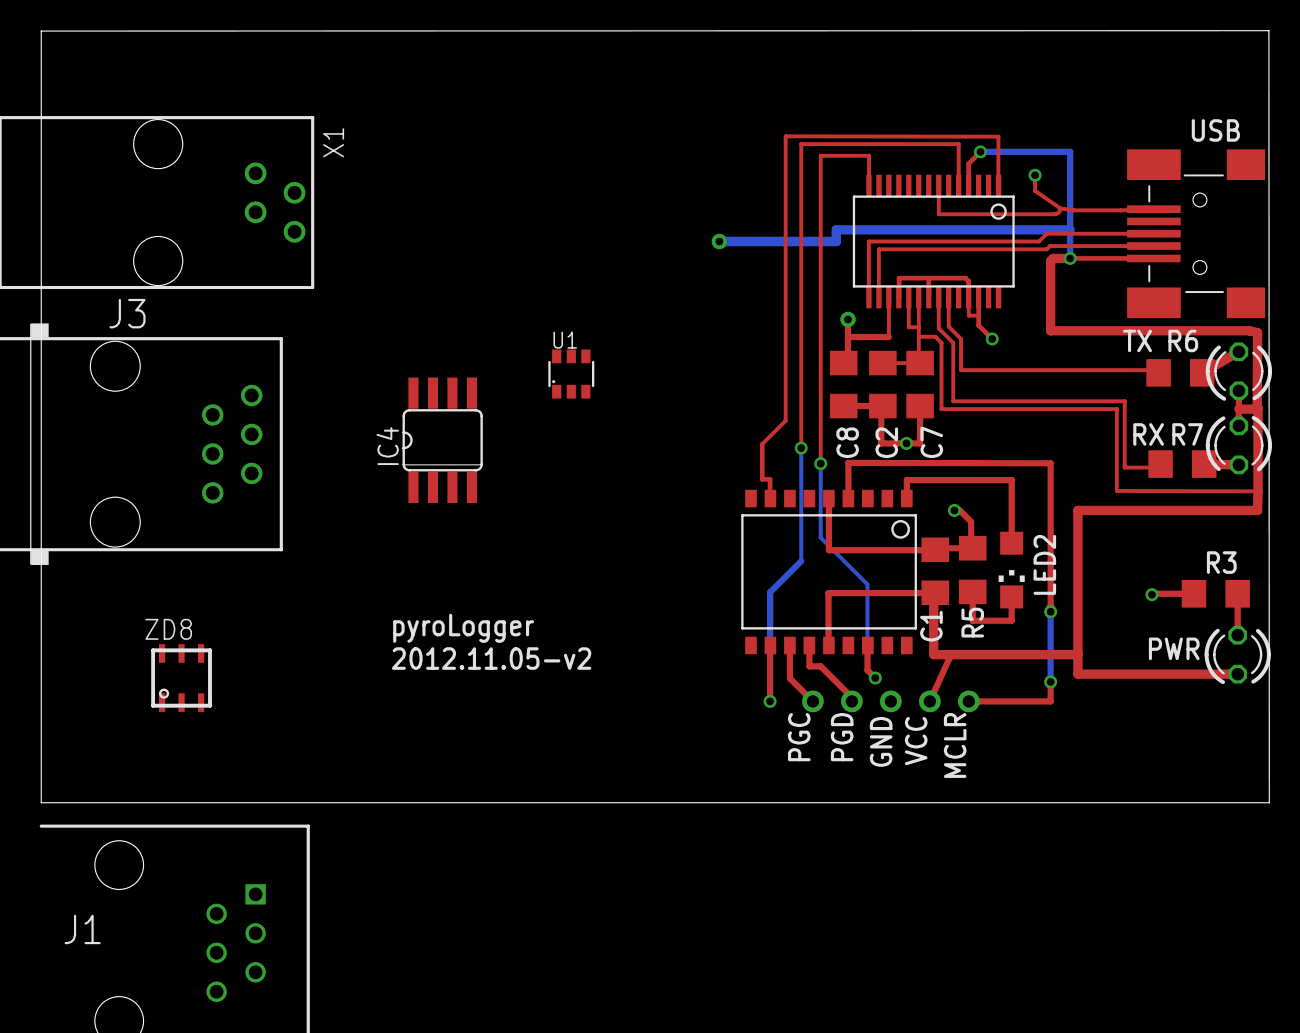
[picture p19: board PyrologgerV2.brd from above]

Board: 2 copper layers, 80.7 x 50.3 mm, 26 parts (0 on the bottom side), 18 nets.

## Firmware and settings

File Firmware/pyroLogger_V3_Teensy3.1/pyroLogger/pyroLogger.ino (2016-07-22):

#include <Arduino.h>
#include <MegunoLink.h>
#include "CommandParser.h"  //A local version of this library changes from the original may exist
#include <OneWire.h>
#include "DallasTemperature.h"
#include <SPI.h>
//#include <SdFat.h>

InterfacePanel Panel;
//SdFat sd;
//SdFile myFile;




// Data wire is plugged into port 2 on the Arduino
#define ONE_WIRE_BUS 2
//#define ONE_WIRE_BUS 3

#define TEMPERATURE_PRECISION 12 //Not sure what this is doing yet, needs research seems to default to 12 always

// Setup a oneWire instance to communicate with any OneWire devices (not just Maxim/Dallas temperature ICs)
OneWire oneWire(ONE_WIRE_BUS);

// Pass our oneWire reference to Dallas Temperature. 
DallasTemperature sensors(&oneWire);

// arrays to hold device addresses
DeviceAddress frontThermometer, backThermometer;
uint8_t myScratchpad;

//Some Variables to Hold the Temperatures
float tempF;
float tempC;
float front;
float back;

//Averaging Variables
float frontAverage;
float backAverage;
float frontAverageArray[25];
float backAverageArray[25];
int averageCount=0;
int dataLength = 0;

//Status Variables Control the ON off State of functionality from MeguinoLinkPro
int averageStatus=0; //0=Averaging OFF 1=Averaging ON
int tempStatus=1; //0=Celsius 1=Fahrenheit start condition - can be changed in GUI also
int filterStatus=1; //0=Filter Data is Off 1=Filter Data is on
int loggingStatus=0; //0=Logging is Off 1=Filter Logging is on
int fileCounter = 0;

//For the MeguinoLinkPro time plots
long LastSent;  // Millis value when the data was last sent. 
int SendInterval = 3000; // Interval (milliseconds) between sending analog data - can be changed in GUI also
TimePlot PyroPlot;  // Name of the Meguino Plot Window where data will be sent

//For the status LED
int LED = 6;

//Get the MLP command parser up and running
MLP::CommandParser<> Parser;


//All Thy Functions doth Lie ;) Below
float rollingAverage(float *store, int size, float entry)
{
	int l;
	float total = 0;
	float result;

	for(l=0; l<size-1; l++)
	{
		store[l] = store[l+1];
		total += store[l];
	}
	store[size-1] = entry;
	total += entry;
	result = total / (float)size;

	return result;
}

void DoSetTempC(MLP::CommandParameter &Parameter)
{
  Serial.print(F("Setting TempType to C"));
  tempStatus=0;
  
      DoStatusUpdate();
  
}

void DoSetTempF(MLP::CommandParameter &Parameter)
{
  Serial.print(F("Setting TempType to F"));
  tempStatus=1;
  
      DoStatusUpdate();
  
  
  
}

void DoSampleRate(MLP::CommandParameter &Parameter)
{
  const char *pchValue;

  pchValue = Parameter.NextParameter();
  if (pchValue == NULL)
  {
    Serial.println(F("Set interval missing parameter"));
    return;
  }

  SendInterval = atoi(pchValue);
  
  DoStatusUpdate();
}

void DoAveragingON(MLP::CommandParameter &Parameter)
{
	const char *pchValue;

	pchValue = Parameter.NextParameter();
	if (pchValue == NULL)
	{
		Serial.println(F("Averaging Data Points missing parameter"));
		return;
	}

	
	Serial.println(F("Turning On Averaging"));
	dataLength = atoi(pchValue);
	averageStatus = 1; //Turn on the Averaging later in the code
	
	DoStatusUpdate();
	
	
	
}

void DoAveragingOFF(MLP::CommandParameter &Parameter)
{
	
	Serial.println(F("Turning OFF Averaging"));
	averageStatus = 0; //Turn off the Averaging later in the code
	
	DoStatusUpdate();
	
}

void DoLoggingOFF(MLP::CommandParameter &Parameter)
{
	
	Serial.println(F("Turning OFF Logging"));
	loggingStatus = 0; //Turn off logging later in the code
	
	DoStatusUpdate();
	
	
	
}

/*
void DoLogggingON(MLP::CommandParameter &Parameter)
{
	
	Serial.println(F("Turning ON Logging"));
	// initialize the SD card at SPI_HALF_SPEED to avoid bus errors with
	// breadboards.  use SPI_FULL_SPEED for better performance.
	if (!sd.begin (10, SPI_HALF_SPEED))
	  {
		  Serial.println(F("SD Communication Error"));
		  return;  // failed to start
	  }
	loggingStatus = 1; //Turn on Logging later in the code
	fileCounter = 0; //Reset the file counter
	
	DoStatusUpdate();
	
	
}
*/

void DoStatusUpdate(){
	//Update Status Table
	
	//Clear the Table
	Serial.print("{TABLE");
		Serial.print("|CLEAR|");
	Serial.println("}");
	
	
	//Update Table Temperature Status
	if (tempStatus == 1){
		Serial.print("{TABLE");
			Serial.print("|SET|");
			Serial.print("Temperature");
			Serial.print("|");
			Serial.print("Fahrenheit");
		Serial.println("}");
	}
	if (tempStatus == 0){
		Serial.print("{TABLE");
			Serial.print("|SET|");
			Serial.print("Temperature");
			Serial.print("|");
			Serial.print("Celcius");
		Serial.println("}");
	}
	
	//Update Table Sample Rate
	Serial.print("{TABLE");
		Serial.print("|SET|");
		Serial.print("Sample Rate");
		Serial.print("|");
		Serial.print(SendInterval / 1000);
		Serial.print("|");
		Serial.print("Seconds");
		
		
	Serial.println("}");
	
	
	//Update Table Average Status
	if (averageStatus == 1){
		Serial.print("{TABLE");
			Serial.print("|SET|");
			Serial.print("Averaging");
			Serial.print("|");
			Serial.print("ON");
			Serial.print("|");
			Serial.print("Points ");
			Serial.print(dataLength);
		Serial.println("}");
	}
	
	if (averageStatus == 0) {
		Serial.print("{TABLE");
			Serial.print("|CLEAR|");
			Serial.print("Averaging");
		Serial.println("}");
		
		Serial.print("{TABLE");
			Serial.print("|SET|");
			Serial.print("Averaging");
			Serial.print("|");
			Serial.print("OFF");
		Serial.println("}");
	}
	
	//Update Table Logging Status
	if (loggingStatus == 1) {
		Serial.print("{TABLE");
			Serial.print("|SET|");
			Serial.print("SD Logging");
			Serial.print("|");
			Serial.print("ON");
		Serial.println("}");
	}
	
	if (loggingStatus == 0) {
		Serial.print("{TABLE");
			Serial.print("|SET|");
			Serial.print("SD Logging");
			Serial.print("|");
			Serial.print("OFF");
		Serial.println("}");
	}
}


// function to print a device address
void printAddress(DeviceAddress deviceAddress)
{
  for (uint8_t i = 0; i < 8; i++)
  {
    // zero pad the address if necessary
    if (deviceAddress[i] < 16) Serial.print("0");
    Serial.print(deviceAddress[i], HEX);
  }
}

// function to read the scratchpad for a device
void printScratchpad(DeviceAddress deviceAddress,uint8_t* myScratchpad)
{
	sensors.readScratchPad(deviceAddress,myScratchpad);
	//Serial.print("Temp C: ");
	
}

// function to print the temperature for a device
void printTemperature(DeviceAddress deviceAddress)
{
  float tempC = sensors.getTempC(deviceAddress);
  Serial.print("Temp C: ");
  Serial.print(tempC);
  Serial.print(" Temp F: ");
  Serial.print(DallasTemperature::toFahrenheit(tempC));
}

// function to print a device's resolution
void printResolution(DeviceAddress deviceAddress)
{
  Serial.print("Resolution: ");
  Serial.print(sensors.getResolution(deviceAddress));
  Serial.println();    
}

// main function to print information about a device
void printData(DeviceAddress deviceAddress)
{
  Serial.print("Device Address: ");
  printAddress(deviceAddress);
  Serial.print(" ");
  printTemperature(deviceAddress);
  Serial.println();
}


void setup(void)
{
  // start serial port
  Serial.begin(57600);
  Serial.println("Dallas Temperature IC Control Library Demo");
  
  pinMode(LED, OUTPUT);

  // Start up the library
  sensors.begin();
delay(5000);
  // locate devices on the bus
  Serial.print("Locating devices...");
  Serial.print("Found ");
  Serial.print(sensors.getDeviceCount(), DEC);
  Serial.println(" devices.");

  // report parasite power requirements
  Serial.print("Parasite power is: "); 
  if (sensors.isParasitePowerMode()) Serial.println("ON");
  else Serial.println("OFF");

  // assign address manually.  the addresses below will need to be changed
  // to valid device addresses on your bus.  device address can be retrieved
  // by using either oneWire.search(deviceAddress) or individually via
  // sensors.getAddress(deviceAddress, index)
  //insideThermometer = { 0x28, 0x1D, 0x39, 0x31, 0x2, 0x0, 0x0, 0xF0 };
  //outsideThermometer   = { 0x28, 0x3F, 0x1C, 0x31, 0x2, 0x0, 0x0, 0x2 };

  // search for devices on the bus and assign based on an index.  ideally,
  // you would do this to initially discover addresses on the bus and then 
  // use those addresses and manually assign them (see above) once you know 
  // the devices on your bus (and assuming they don't change).
  // 
  // method 1: by index
  if (!sensors.getAddress(frontThermometer, 0)) Serial.println("Unable to find address for Device 0"); 
  if (!sensors.getAddress(backThermometer, 1)) Serial.println("Unable to find address for Device 1"); 

  // method 2: search()
  // search() looks for the next device. Returns 1 if a new address has been
  // returned. A zero might mean that the bus is shorted, there are no devices, 
  // or you have already retrieved all of them.  It might be a good idea to 
  // check the CRC to make sure you didn't get garbage.  The order is 
  // deterministic. You will always get the same devices in the same order
  //
  // Must be called before search()
  //oneWire.reset_search();
  // assigns the first address found to insideThermometer
  //if (!oneWire.search(insideThermometer)) Serial.println("Unable to find address for insideThermometer");
  // assigns the seconds address found to outsideThermometer
  //if (!oneWire.search(outsideThermometer)) Serial.println("Unable to find address for outsideThermometer");

  // show the addresses we found on the bus
  Serial.print("Device 0 Address: ");
  printAddress(frontThermometer);
  Serial.println();

  Serial.print("Device 1 Address: ");
  printAddress(backThermometer);
  Serial.println();

  // set the resolution to 12 bit
  sensors.setResolution(frontThermometer, TEMPERATURE_PRECISION);
  sensors.setResolution(backThermometer, TEMPERATURE_PRECISION);

  Serial.print("Device 0 Resolution: ");
  Serial.print(sensors.getResolution(frontThermometer), DEC); 
  Serial.println();

  Serial.print("Device 1 Resolution: ");
  Serial.print(sensors.getResolution(backThermometer), DEC); 
  Serial.println();


  //Interface Control Panel 
  Parser.AddCommand(F("SetTempC"), DoSetTempC);
  Parser.AddCommand(F("SetTempF"), DoSetTempF);
  Parser.AddCommand(F("SampleRate"),DoSampleRate);
  Parser.AddCommand(F("AveragingON"),DoAveragingON);
  Parser.AddCommand(F("AveragingOFF"),DoAveragingOFF);
 // Parser.AddCommand(F("LoggingOFF"),DoLoggingOFF);
 // Parser.AddCommand(F("LoggingON"),DoLogggingON);
  
 
	  
  }




void loop(void)
{ 
  //Process any commands from MLP
  Parser.Process();



  if ((millis() - LastSent) > SendInterval) //Enough Time Has passed so take the readings now
  {
     
	
	digitalWrite(LED, HIGH); //Turn on the status LED
    sensors.requestTemperatures(); //Ask for the temperatures
	
	
    
    tempC = sensors.getTempC(frontThermometer);
    tempF = DallasTemperature::toFahrenheit(tempC);
	
	if (averageStatus == 1 && tempStatus == 1){
		frontAverage=rollingAverage(frontAverageArray,dataLength,tempF);
		front = frontAverage;
	}
	
	if (averageStatus == 1 && tempStatus == 0){
		frontAverage=rollingAverage(frontAverageArray,dataLength,tempC);
		front = frontAverage;
	}
	
	if (averageStatus == 0 && tempStatus == 1){
		front = tempF;
	}
	
	if (averageStatus == 0 && tempStatus == 0){
		front = tempC;
	}
	PyroPlot.SendData("Front", front, TimePlot::Blue, TimePlot::Solid, 1 , TimePlot::NoMarker);
    
    //Update MeguinoLinkPro Plot Window
    tempC = sensors.getTempC(backThermometer);
    tempF = DallasTemperature::toFahrenheit(tempC);

    if (averageStatus == 1 && tempStatus == 1){
	    backAverage=rollingAverage(backAverageArray,dataLength,tempF);
	    back = backAverage;
    }
    
    if (averageStatus == 1 && tempStatus == 0){
	    backAverage=rollingAverage(backAverageArray,dataLength,tempC);
	    back = backAverage;
    }
    
    if (averageStatus == 0 && tempStatus == 1){
	    back = tempF;
    }
    
    if (averageStatus == 0 && tempStatus == 0){
	    back = tempC;
    }
	PyroPlot.SendData("Back", back, TimePlot::Red, TimePlot::Solid, 1 , TimePlot::NoMarker);
/*
	if (loggingStatus == 1){
		// open the file for write at end like the Native SD library
		if (!myFile.open ("pyro.txt",  O_CREAT | O_WRITE | O_APPEND))
		{
			Serial.println(F("File Error"));
			return;  // failed to start
		}
	        myFile.print(fileCounter);
		myFile.print (",     ");
  	myFile.print(front);
		myFile.print (",     ");
		myFile.print (back);
		myFile.println();
		myFile.close();
		fileCounter = fileCounter + 1;
	}
 */
    
	

    //Print to the Message Monitor Window in MeguinoLinkPro
    Serial.print("{MESSAGE:");
	Serial.print("TemperatureFeed");
	Serial.print("|data|");
	Serial.print("Front ");
	Serial.print(front);
    Serial.print("\tBack ");
	Serial.print(back);
	Serial.println("}");
	
	
     DoStatusUpdate();
	 
	 //Turn off the Status LED
	 digitalWrite(LED, LOW); //Turn off the status LED
	 
	 //Reset Millis here at the end for more accurate timing
	 LastSent = millis();
     

	//Some Debug Poop
	
	//Serial.print("Device 0 Resolution: ");
	//Serial.print(sensors.getResolution(frontThermometer), DEC);
	//Serial.println();
	

  }

  
}

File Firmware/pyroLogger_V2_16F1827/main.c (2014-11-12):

//Capture Code
//Last Update ====> Feb 2012
#include <16F1827.h>
#use delay(clock=8000000)
#fuses NOWDT,INTRC_IO, NOPROTECT, NOBROWNOUT, NOMCLR, NOCPD, PUT, NOIESO, NOFCMEN, PLL_SW
#use rs232(baud=19200,parity=N,xmit=PIN_B5,rcv=PIN_B2,bits=8)

//Setup I2C
#use i2c(master, sda=PIN_B1, scl=PIN_B4)
#define Device_SDA PIN_B1
#define Device_SLC PIN_B4

//Include Driver File
#include<ds2482-V2.c>

//Variable Declaration
int1 interactive=0;
int8 result;
int8 i,status;
char command;
int8 dataArray[6];
int32 CapValue;
float32 pF;

//********************************************************************************
//Functions
//********************************************************************************

//Blinker Code for the indicator LED
void blink(){
output_high(PIN_A2);
delay_ms(250);
output_low(PIN_A2);
delay_ms(250);
}

void main(){
setup_oscillator (OSC_8MHZ);
setup_timer_1(T1_DISABLED);
setup_adc_ports(NO_ANALOGS|VSS_VDD);
setup_adc(ADC_OFF);
setup_comparator(NC_NC_NC_NC);
setup_vref(FALSE);

// Give indiction that the microcontroller is up and running
for (i=0;i<5;i++){
blink();
}

//On boot interactive mode is on so that the user can use a terminal interface
interactive = 1;

//Main loop starts here...
while(true){  //Waits for a command to come in over the serial port in interactive mode   
if (interactive == 1)
   printf("Please enter a command (h for help):\n\r");

command = getc();

switch (command){
case 'i':  //Turn off interactive mode
   printf("Turning Off Interactive...\n\r");
   interactive = 0;
   printf("Done...\n\r");
   break;
   
case 'r':  //Reset DS2482
   if (interactive == 1){
      printf("Resetting the DS2482\n\r");
   }
   //Do the Reset
   result = ds2482_reset();
   
   if (interactive == 1){
      if (result == 1)
         printf("...Success...\n\r");
      else printf ("...Fail..\n\r");
   }
   break;
   
case 'c':  //Configure DS2482
//Active pullup should always be selected unless
//there is only a single slave on the 1-Wire line.
//0x01 1WS Disabled, SPU Disabled, 0 NC, APU Active Pullup (Normal Operation for more then one device on onewire bus)
//0x05 1WS Disabled, SPU Active, 0 NC, APU Active Pullup (Strong pullup is commonly used with 1-Wire parasitically powered temperature sensors, eeprom, A/D converters)

   if (interactive == 1){
      printf("Configuring the DS2482\n\r");
   }
   
   //Do the Config
   result = ds2482_write_config(0x01);
   
   if (interactive == 1){
      if (result == 1)
         printf("...Success...\n\r");
      else printf ("...Fail..\n\r");
   }
   break;
   
case 'R':  //Reset One Wire Bus
   if (interactive == 1){
      printf("Resetting the One Wire\n\r");
   }
   
   result = OWreset();
   
   if (interactive == 1){
      if (result == 1)
         printf("...Success...\n\r");
      else printf ("...Fail..\n\r");
   }
   break;
   
case 'n': //Read the Network Address
OWreset();
delay_ms(1);
OWWriteByte("33");
//delay_ms(20);

for(i=0; i<=7; i++) {
result = OWReadByte();
printf ("%2X",result);
delay_ms(1);
}

break;

case 's': //Read the OW status register
OWreset();
delay_ms(1);
OWWriteByte(204);  //Transmit skip Rom Command CC = 204
OWWriteByte(105);  //0x69 Transmit Read RAM command
OWWriteByte(1); //Transmit Read start address
result=OWReadByte();

break;
  


case 'f': //Fix the floating power switch

OWreset();
OWWriteByte(0xCC);
OWWriteByte(0x6C);    //Write Data Command
OWWriteByte(0x31);    //Eeprom address but actually gets written to Shadow Ram
OWWriteByte(0xE7);    //Value to make PMOD1 SWEN=0 RNAOP=0

//Copy the shadow Ram written above over to actual EEPROM
OWreset();
OWWriteByte(0xCC);
OWWriteByte(0x48);    //send the copy command
OWWriteByte(0x30);    //copy shadow ram to the block containing 31

break;   
   
   
   
default:  //Displays help message if you get an 'h' or an unknown command
   printf("PyroLogger Board Found and Responding...\n\r");
   printf("Firmware Version 2\n\r");
   printf("Interactive Mode is ON\n\r");
   printf("\n\r");
   printf("\n\r");
   printf("Command List:\n\r");
   printf("h = System Help\n\r");
   printf("i = Exit ineractive mode\n\r");
   printf("r = Reset DS2482\n\r");
   printf("c = Configure DS2482\n\r");
   printf("R = Reset One Wire Bus\n\r");
   printf("N = Print Net Address\n\r");
  
}

}
}

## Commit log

2008-03-13 This is the first update since switching over to wxpython. Migration went pretty smoothly. Lots more capability without much of a sacrafice. I like it!!!
2008-03-17 Added buttons fixed multiple subplot problems, doesn't eat up CPU any more!
    [wxthermo.py]
2008-06-06 Finally got everything into sizers, updated thermometer class, also added a couple of status boxes.
2008-12-02 Not much changed just updated the old pyrologger file, but failed to get it to work in time for Rogers fireing, maybe next time.
    [pyro_log.py]
2009-03-27 This is a major rewrite. Mainly for two instead of one thermocouple. Also lots of bug fixes.
    [custom_widget.py, slider.py, stripcharting.py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]
2009-04-21 Add the serial port search feature and quit button now works, more code cleanup, installed eclipse and pydev pluggin
2011-10-20 Just some house cleaning after moving over to GitHub from GoogleCode. I added some README's got rid of some old files. Added the board files and changed some folder names etc...
    [16F88_FT232RL.brd, 16F88_FT232RL.sch, ds2460.sch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]
2011-10-26 Changed the thermocouple coefficients for the ambient sensors and added a low and high set for the thermocouples. Pretty major overhaul and still testing. Going to know more after this fireing. The p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
2014-11-12 Added V2 stuff to repo duckies in a row for another development stab
    [16F88_FT232RL.brd, 16F88_FT232RL.sch, Lookup.xls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]
2014-11-13 More Ogranizing
    [PyroLogger BOM.xlsx]
2014-12-29 adding in the new working teensy software before I start piddling about making changes. This commit works and is pretty solid though not feature rich.
2014-12-31 Added Temperature conversion buttons and a sample rate button to the new interface panel, changes to micro code plus MLP GUI.
2015-02-12 Updating with a new Kicad schematic for the teensy version of the pyrologger. Not complete yet but close
    [Pyrologger_V3.kicad_pcb, Pyrologger_V3.sch]
2015-05-14 finished off the kicad board file and starting to work on the arduino code
    [Pyrologger_V3.kicad_pcb, Pyrologger_V3.sch]
2015-05-22 Switched to the Visual Micro Atmel code editor, board files updated, general code cleanup and first stab rolling average filter.
2015-06-04 Some enclosure attempts and GUI update with a status update, general code clean up.
2015-06-04 Pushing up Enclosure files and GUI status additions. SD card access at least for logging data is basically working also.
    [PyroEnclosureTop.stl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]
2015-06-04 Updating the stl files for the enclosure gcode may still change but for now matches
    [PyroEnclosureTop.stl, Pyrologger_V3_Board.stl, Pyrologger_V3_Enclosure_Bottom.stl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]
2015-06-30 Changed link to right board on Adafruit
2016-07-22 adding all the code for the teensy
